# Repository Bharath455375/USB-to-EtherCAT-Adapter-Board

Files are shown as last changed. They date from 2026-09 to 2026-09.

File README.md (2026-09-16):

## USB-to-EtherCAT-Adapter-Board

A USB-to-EtherCAT Adapter Board V1.0, intended to provide communication between a USB host system and an EtherCAT 
network. The board combines an STM32F411CEUx microcontroller for USB interfacing 
and control with the LAN9252 EtherCAT controller for handling EtherCAT
communication. It provides a compact hardware interface for converting USB communication into EtherCAT communication, making it suitable for industrial automation applications.

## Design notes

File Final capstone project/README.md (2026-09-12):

 <div align="center" style="border: 2px solid #ccc; padding: 20px; border-radius: 12px; width: 80%; margin: auto; box-shadow: 0 0 10px rgba(0,0,0,0.15);">
    Logo - SURE ProEd

  <h1 align="center" style="font-family: Arial; font-weight: 600; margin-top: 15px;">SURE ProEd (formerly SURE Trust) 
      </h1>
<h2 style="color: #2b6cb0; font-family: Arial;">Skill Upgradation for Rural youth Empowerment Trust</h2>
</div>

<hr style="border: 0; border-top: 1px solid #ccc; width: 80%;" />

<div style="padding: 20px; border: 2px solid #ddd; border-radius: 12px; width: 90%; margin: auto; background: #fafafa; font-family: Arial;">

<h2 style = "color:#333;"> Student Details </h2>
<div align = "left" style ="margin: 20px; font-size: 16px;">
    <p><strong>Name:</strong> Sangam Bharath Kumar </p>
    <p><strong>Email ID:</strong> bharathkumargpcb@gmail.com </p>
    <p><strong>College Name:</strong> MVSR Engineering College </p>
    <p><strong>Branch/Specialization :</strong> Electronics and Communication Engineering </p>
    <p><strong>College ID:</strong> 2451-23-735-022 </p>
</div>

<hr style="border: 0; border-top: 1px solid #ccc; width: 80%;" />

<h2 style="color:#333;"> Course Details </h2>
<div align="left" style="margin: 20px; font-size: 16px;">
    <p><strong>Course Opted:</strong> PCB Design </p>
    <p><strong>Instructor Name:</strong> C Paramesh Kumar </p>
</div>
<div align="left" style="margin: 20px; font-size: 16px;">
    <p><strong>Duration:</strong> 6 months </p>

<hr style="border: 0; border-top: 1px solid #ccc; width: 80%;" />

<h2 style="color:#333;"> Trainer Details </h2>
<div align="left" style="margin: 20px; font-size: 16px;">

<p><strong>Trainer Name:</strong> C Paramesh Kumar </p>
<p><strong>Trainer Email ID:</strong> parameshkumar432@gmail.com </p>
<p><strong>Trainer Designation:</strong> Hardware Design Engineer-RC Labs</p>

<hr style="border: 0; border-top: 1px solid #ccc; width: 80%;" />

## **Table of Contents**
- [Course Learning](#course-learning-to-be-edited-by-student)
- [Projects Completed](#projects-completed)
- [Project Introduction](#project-introduction)
- [Technologies Used](#technologies-used)
- [Roles and Responsibilities](#roles-and-responsibilities)
- [Project Report](#project-report)
- [Learnings from LST & SST](#learnings-from-lst--sst)
- [Community Services](#community-services)
- [Certificate](#certificate)
- [Acknowledgments](#acknowledgments)

<hr style="border: 0; border-top: 1px solid #ccc; width: 80%;" />

## Overall Learning 

During my six-month internship under a trust in the field of PCB Design, I gained practical knowledge and hands-on experience in the complete PCB development process. I learned the fundamentals of schematic design, component selection, PCB layout, routing, design-rule checking (DRC), and Gerber file generation.
Overall, the internship strengthened my understanding of electronics hardware design, PCB fabrication requirements, documentation, and systematic problem-solving, while improving my technical skills and confidence in working on real-world PCB projects.

<h2 style="color:#333;"> Projects Completed </h2>
<div align="left" style="margin: 20px; font-size: 16px;">

<p><strong><a href="#project1">Project 1:</a></strong> &lt; USB to EtherCAT Adapter Board V1.0 &gt;</p>

</div>

<h3 id="project1">Project 1: USB to EtherCAT Adapter Board V1.0</h3>
<p>
  USB to EtherCAT adapter board is a communication interface that enables a PC or embedded system with a USB port to communicate with EtherCAT-based industrial devices. During the work, I gained an understanding of the board’s USB interface, EtherCAT communication, Ethernet PHY, RJ45 connectors, power supply, and supporting circuitry.
</p>
<p>
  <a href="https://drive.google.com/file/d/1o7Rr3_MuH4V35tEqP3frIHMUUnw0U5oj/view?usp=sharing" target="_blank"><strong>→ View Full Project Report</strong></a>

<hr style="height:1px; border-top:1px solid #ccc; width:80%;" />

## **Learnings from LST and SST**

The life skills training and SST provided valuable lessons that helped me improve both personally and professionally. During the training, I learned the importance of effective communication, teamwork, time management, problem-solving, and decision-making. I understood how clear communication and active listening can help in building better relationships and avoiding misunderstandings.

The training also helped me develop confidence, leadership qualities, adaptability, and a positive attitude.
## **Community Services**

During my internship period, I participated in multiple community-oriented activities.

### **Activities Involved**
  
Badangpet
- **Tree Plantation Drive** – Participated by planting trees and contributing to environmental improvement.

Badangpet
- **Helping Elder Citizens** – Assisted two elderly individuals with simple daily tasks and provided support where needed.

### **Impact / Contribution**
- Actively participated in promoting a greener and cleaner surroundings.
- Offered personal assistance to elder citizens, strengthening community bonds.
- Improved skills in communication, coordination, and social responsibility.

### **Photos**

<div align="center">
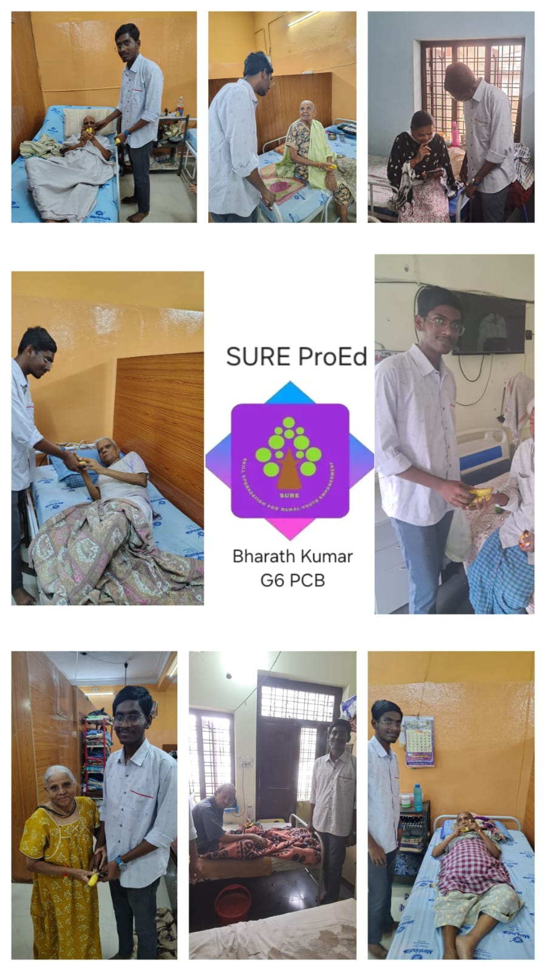
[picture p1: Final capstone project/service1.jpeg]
Community Service Photo 1

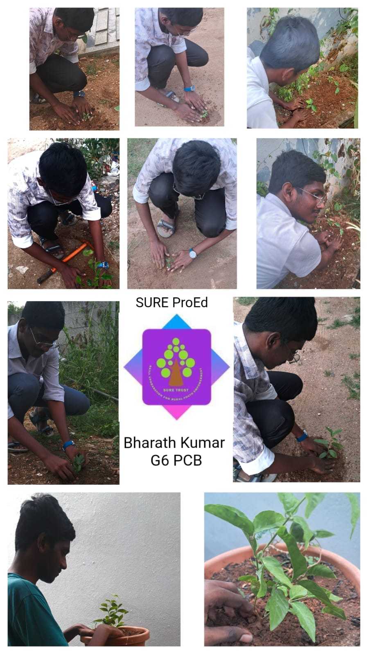
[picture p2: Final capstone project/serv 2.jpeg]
Community Service Photo 2

</div>

---

## **Certificate**

The internship certificate serves as an official acknowledgment of the successful completion of my training period. It will be issued by the organization upon fulfilling all required tasks and meeting the performance expectations of the program. The certificate validates the skills, experience, and contributions made during the internship.

<p align="center">
Internship Certificate
</p>

---

## **Acknowledgments**

I would like to express my sincere gratitude to everyone who supported and guided me throughout my internship on PCB Design.

I am thankful to SURE ProEd and Radha Kumari ma'am for providing me with the opportunity to undergo this internship and gain valuable practical knowledge in PCB design and development.

I would like to express my special thanks to Paramesh Kumar sir for his valuable guidance, technical support, and encouragement throughout the internship. Their practical insights helped me improve my understanding of PCB design and its applications in real-world electronic systems.

- [Prof. Radhakumari Challa](https://www.linkedin.com/in/prof-radhakumari-challa-a3850219b) , Executive Director and Founder - [SURE Trust](https://www.suretrustforruralyouth.com/)

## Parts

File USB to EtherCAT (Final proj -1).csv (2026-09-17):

Reference | Qty | Value | DNP | Exclude from BOM | Exclude from Board | Footprint | Datasheet
C1,C2,C21,C22 | 4 | 12pF
C3,C4,C5,C6,C7,C8,C11,C12,C13,C14,C15,C16,C17,C18,C19,C20,C24,C27,C28,C29,C30,C31,C32 | 23 | 0.1uF
C9 | 1 | 1uF
C10 | 1 | 470pF
C23 | 1 | 2.2uF
C25,C26 | 2 | 0.022uF
D1,D3 | 2 | LED
D2 | 1 | ESD9B5.0ST5G |  |  |  | Diode_SMD:D_SOD-923 | https://www.onsemi.com/pub/Collateral/ESD9B-D.PDF
FB1,FB2,FB3,FB4,FB5 | 5 | FerriteBead
J1 | 1 | Conn_01x04
J2,J3 | 2 | RJ45_Hanrun_HR911105A_Horizontal |  |  |  | Connector_RJ:RJ45_Hanrun_HR911105A_Horizontal | https://datasheet.lcsc.com/lcsc/1811141815_HANRUN-Zhongshan-HanRun-Elec-HR911105A_C12074.pdf
J4 | 1 | USB_A
R1,R8,R19,R23 | 4 | 220R
R2,R4,R5 | 3 | 10K
R3 | 1 | 12.1K
R6,R7 | 2 | 10R
R9,R10,R11,R12,R13,R14,R15,R16,R17,R18 | 10 | 49.9R
R20,R21,R22 | 3 | 4.7k
SW1 | 1 | SW_Push
U1 | 1 | LAN9252 |  |  |  | LAN9252_PT:QFP50P1200X1200X120-65N
U2 | 1 | STM32F411CEUx |  |  |  | Package_DFN_QFN:QFN-48-1EP_7x7mm_P0.5mm_EP5.6x5.6mm | https://www.st.com/resource/en/datasheet/stm32f411ce.pdf
U3 | 1 | 24FC512-I_SM |  |  |  | 24FC512-I_SM:SOIC127P794X203-8N
U4 | 1 | AMS1117-3.3 |  |  |  | Package_TO_SOT_SMD:SOT-223-3_TabPin2 | http://www.advanced-monolithic.com/pdf/ds1117.pdf
Y1,Y3 | 2 | 25KHz
Y4 | 1 | 32KHz

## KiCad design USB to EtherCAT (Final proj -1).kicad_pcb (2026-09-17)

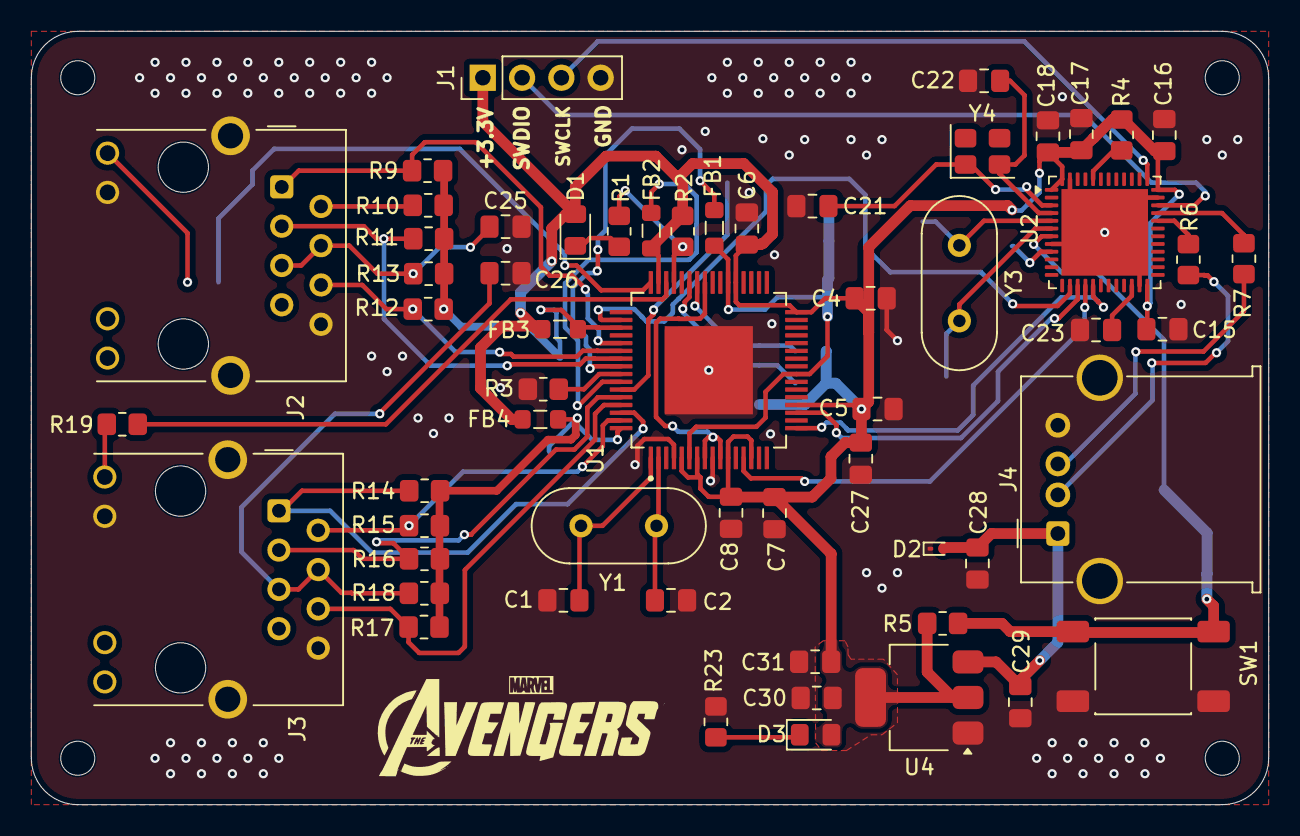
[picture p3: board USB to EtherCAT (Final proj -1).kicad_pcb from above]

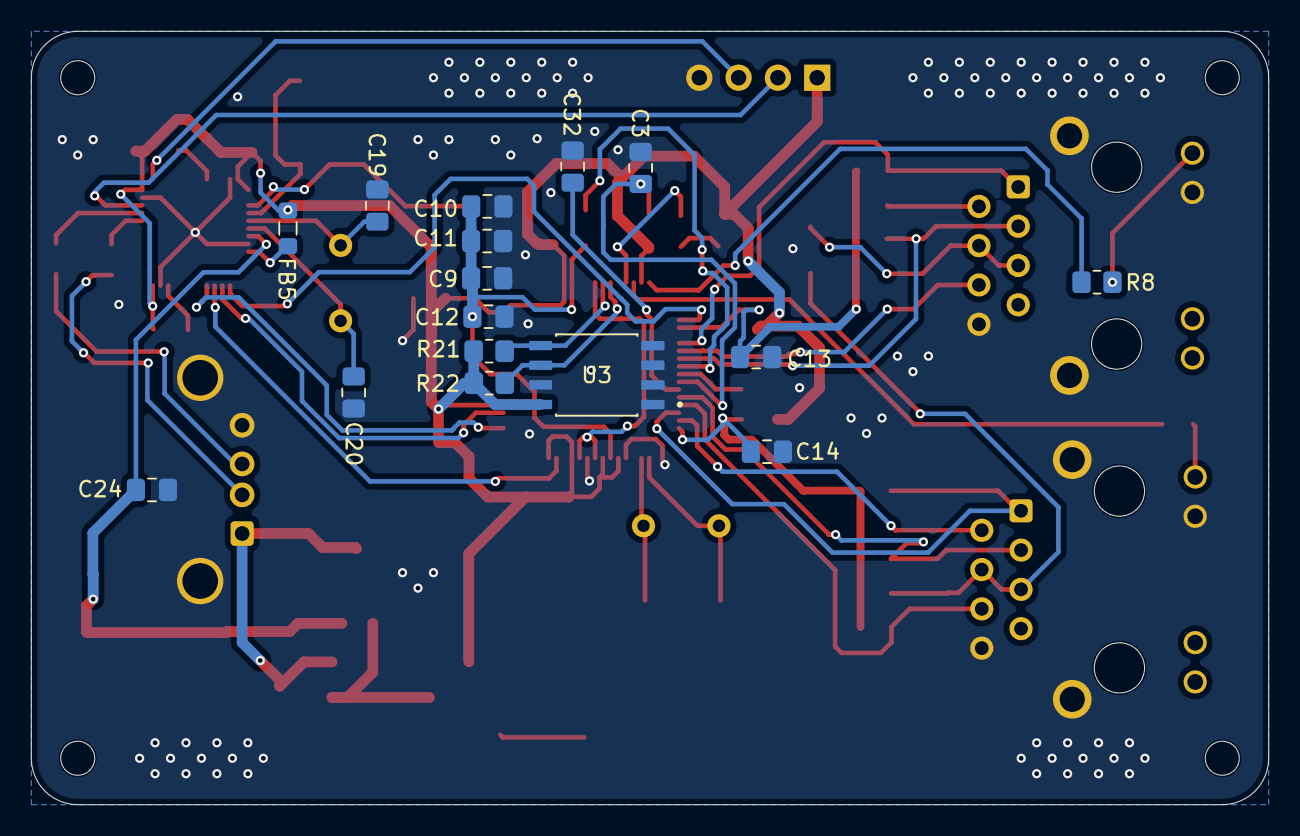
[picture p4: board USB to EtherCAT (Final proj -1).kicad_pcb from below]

Board: 2 copper layers, 80.0 x 50.0 mm, 78 parts (16 on the bottom side), 50 nets.

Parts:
C1, C2, C21, C22: 12pF; C_0805_2012Metric_Pad1.18x1.45mm_HandSolder
C3, C4, C5, C6, C7, C8, C11, C12, C13, C14, C15, C16, C17, C18, C19, C20, C24, C27, C28, C29, C30, C31, C32: 0.1uF; C_0805_2012Metric_Pad1.18x1.45mm_HandSolder
C9: 1uF; C_0805_2012Metric_Pad1.18x1.45mm_HandSolder
C10: 470pF; C_0805_2012Metric_Pad1.18x1.45mm_HandSolder
C23: 2.2uF; C_0805_2012Metric_Pad1.18x1.45mm_HandSolder
C25, C26: 0.022uF; C_0805_2012Metric_Pad1.18x1.45mm_HandSolder
D1, D3: LED; LED_0805_2012Metric_Pad1.15x1.40mm_HandSolder
D2: ESD9B5.0ST5G; D_SOD-923
FB1, FB2, FB3, FB4, FB5: FerriteBead; L_0805_2012Metric_Pad1.05x1.20mm_HandSolder
H1, H2, H3, H4: MountingHole; MountingHole_2.2mm_M2
J1: Conn_01x04; PinHeader_1x04_P2.54mm_Vertical
J2, J3: RJ45_Hanrun_HR911105A_Horizontal
J4: USB_A; USB_A_Molex_67643_Horizontal
R1, R8, R19, R23: 220R; R_0805_2012Metric_Pad1.20x1.40mm_HandSolder
R2, R4, R5: 10K; R_0805_2012Metric_Pad1.20x1.40mm_HandSolder
R3: 12.1K; R_0805_2012Metric_Pad1.20x1.40mm_HandSolder
R6, R7: 10R; R_0805_2012Metric_Pad1.20x1.40mm_HandSolder
R9, R10, R11, R12, R13, R14, R15, R16, R17, R18: 49.9R; R_0805_2012Metric_Pad1.20x1.40mm_HandSolder
R21, R22: 4.7k; R_0805_2012Metric_Pad1.20x1.40mm_HandSolder
SW1: SW_Push; SW_Push_1P1T_NO_E-Switch_TL3301NxxxxxG
U1: LAN9252; QFP50P1200X1200X120-65N
U2: STM32F411CEUx; QFN-48-1EP_7x7mm_P0.5mm_EP5.6x5.6mm
U3: 24FC512-I_SM; SOIC127P794X203-8N
U4: AMS1117-3.3; SOT-223-3_TabPin2
Y1, Y3: 25KHz; Crystal_HC49-4H_Vertical
Y4: 32KHz; Crystal_SMD_3225-4Pin_3.2x2.5mm

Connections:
+3.3V: C4.1, C5.1, C6.1, C7.1, C8.1, C15.2, C16.2, C17.2, C18.2, C27.1, C30.1, C31.1, D1.2 (A), D3.2 (A), FB2.2, FB3.1, FB4.1, FB5.2, J1.1, R2.1, R4.1, R5.1, R21.2, R22.1, U1.5 (VDD33), U1.7 (REG_EN), U1.11 (~RST), U1.14 (VDDIO), U1.20 (VDDIO), U1.32 (VDDIO), U1.37 (VDDIO), U1.47 (VDDIO), U2.1 (VBAT), U2.24 (VDD), U2.36 (VDD), U2.48 (VDD), U3.8 (VCC), U4.2 (VO)
+5V: C28.1, C29.1, D2.2 (A2), J4.1 (VBUS), U4.3 (VI)
GND: C1.1, C2.2, C3.2, C4.2, C5.2, C6.2, C7.2, C8.2, C9.2, C10.2, C11.2, C12.2, C13.2, C14.2, C15.1, C16.1, C17.1, C18.1, C19.2, C20.2, C21.2, C22.2, C23.2, C24.2, C25.2, C26.2, C27.2, C28.2, C29.2, C30.2, C31.2, C32.2, D2.1 (A1), J1.4, J2.8, J2.10, J2.SH, J3.8, J3.10, J3.SH, J4.4 (GND), J4.SH (Shield), R3.1, R23.2, SW1.2, U1.4 (OSCVSS), U1.9 (FXSDA/FXLOSA/~FXSDENA), U1.65 (VSS), U2.8 (VSSA), U2.23 (VSS), U2.35 (VSS), U2.47 (VSS), U2.49 (VSS), U3.1 (A0), U3.2 (A1), U3.3 (A2), U3.4 (VSS), U3.7 (WP), U4.1 (GND)
GPIO0: R8.2, U1.48 (LINKACTLED0/TDO/~CHIP_MODE0)
GPIO1: R19.2, U1.46 (LINKACTLED1/TDI/~CHIP_MODE1)
GPIO2: R1.2, R2.2, U1.45 (RUNLED/~E2PSIZE)
I2C_SCL: R22.2, U1.43 (EESCL/TCK), U3.6 (SCL)
I2C_SDA: R21.1, U1.42 (EESDA/TMS), U3.5 (SDA)
unnamed: D1.1 (K), R1.1
unnamed: D3.1 (K), R23.1
unnamed: J2.9, R8.1
unnamed: C25.1, J2.4 (TCT), J2.5 (RCT), R13.1
unnamed: J3.9, R19.1
unnamed: C26.1, J3.4 (TCT), J3.5 (RCT), R18.1
unnamed: C1.2, U1.1 (OSCI), Y1.2
unnamed: C2.1, U1.2 (OSCO), Y1.1
unnamed: R3.2, U1.57 (RBIAS)
unnamed: FB1.2, U1.56 (VDD12TX1)
unnamed: C3.1, FB2.1, U1.58 (VDD33BIAS)
unnamed: R4.2, U2.44 (BOOT0)
unnamed: R6.1, U2.32 (PA11)
unnamed: R7.1, U2.33 (PA12)
unnamed: C21.1, U2.3 (PC14), Y4.1
unnamed: C22.1, U2.4 (PC15), Y4.2
unnamed: C19.1, U2.5 (PH0), Y3.1
unnamed: C20.1, U2.6 (PH1), Y3.2
unnamed: C23.1, U2.22 (VCAP1)
unnamed: FB5.1, U2.9 (VDDA)
RST: C24.1, R5.2, SW1.1, U2.7 (NRST)
RXNA: J2.6 (RD-), R12.1, U1.54 (RXNA)
RXNB: J3.6 (RD-), R17.1, U1.61 (RXNB)
RXPA: J2.3 (RD+), R11.1, U1.55 (RXPA)
RXPB: J3.3 (RD+), R16.1, U1.60 (RXPB)
SCK: U1.19 (D9/AD9/LATCH_IN/SCK), U2.15 (PA5)
SCS: U1.50 (D5/AD5/OUTVALID/SCS#), U2.14 (PA4)
SI: U1.17 (D0/AD0/WD_STATE/SI/SIO0), U2.17 (PA7)
SO: U1.13 (D1/AD1/EOF/SO/SIO1), U2.16 (PA6)
SWCLK: J1.3, U2.37 (PA14)
SWDIO: J1.2, U2.34 (PA13)
TESTMODE: U1.8 (~FXLOSEN), U1.10 (FXSDB/FXLOSB/~FXSDENB), U1.41 (TESTMODE)
TXNA: J2.2 (TD-), R10.1
TXNB: J3.2 (TD-), R15.1, U1.63 (TXNB)
TXPA: J2.1 (TD+), R9.1, U1.53 (TXPA)
TXPB: J3.1 (TD+), R14.1, U1.62 (TXPB)
USB_DN: J4.2 (D-), R6.2
USB_DP: J4.3 (D+), R7.2
VDD12TX: C32.1, U1.59 (VDD12TX2)
VDD33TXRX1: C13.1, FB3.2, R9.2, R10.2, R11.2, R12.2, R13.2, U1.51 (VDD33TXRX1)
VDD33TXRX2: C14.1, FB4.2, R14.2, R15.2, R16.2, R17.2, R18.2, U1.64 (VDD33TXRX2)
VDDCR: C9.1, C10.1, C11.1, C12.1, FB1.1, U1.6 (VDDCR), U1.24 (VDDCR), U1.38 (VDDCR)
